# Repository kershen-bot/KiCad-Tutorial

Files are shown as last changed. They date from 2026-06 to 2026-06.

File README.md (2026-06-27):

# KiCad-Tutorial
I followed a KiCad tutorial, and here is how it went.

First, the tutorial I used was made by Digikey. The link to the Digikey website is "https://www.digikey.ca/," and the link to the tutorial is.
1. https://www.youtube.com/watch?v=0WCi1rhueH4&list=PLEBQazB0HUyQ5YJSdCBb79orXaR3Uk5vm
2. https://www.youtube.com/watch?v=0Q6gU7-QqUg&list=PLEBQazB0HUyQ5YJSdCBb79orXaR3Uk5vm&index=2
3. https://www.youtube.com/watch?v=0MqHR6cU_y0&list=PLEBQazB0HUyQ5YJSdCBb79orXaR3Uk5vm&index=3
4. https://www.youtube.com/watch?v=KN3fHXhNkTU&list=PLEBQazB0HUyQ5YJSdCBb79orXaR3Uk5vm&index=4
5. https://www.youtube.com/watch?v=4YSZwcUSgJo&list=PLEBQazB0HUyQ5YJSdCBb79orXaR3Uk5vm&index=5
6. https://www.youtube.com/watch?v=zdieFtrvjew&list=PLEBQazB0HUyQ5YJSdCBb79orXaR3Uk5vm&index=6
7. https://www.youtube.com/watch?v=zMNGZAnHPts&list=PLEBQazB0HUyQ5YJSdCBb79orXaR3Uk5vm&index=7

The finished Project was these images of a water alarm.




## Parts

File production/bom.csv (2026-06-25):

Designator | Footprint | Quantity | Value | LCSC Part #
BZ1 | Buzzer_D30mm_H20mm_P15_668-1652-ND_AI-3035-TT-12V-R | 1 | Buzzer
C1 | C_Disc_D3.0mm_W1.6mm_P2.50mm | 1 | 1nF
D1 | LED_D5.0mm | 1 | LED_Small_Filled
J1 | BarrelJack_GCT_DCJ200-10-A_Horizontal | 1 | Jack-DC
J2 | TerminalBlock_Phoenix_PT-1,5-2-5.0-H_1x02_P5.00mm_Horizontal | 1 | Screw_Terminal_01x02
Q1 | TO-92_Inline | 1 | 2N7000
R1 | R_Axial_DIN0204_L3.6mm_D1.6mm_P5.08mm_Horizontal | 1 | 10M
R2 | R_Axial_DIN0204_L3.6mm_D1.6mm_P5.08mm_Horizontal | 1 | 6.8k

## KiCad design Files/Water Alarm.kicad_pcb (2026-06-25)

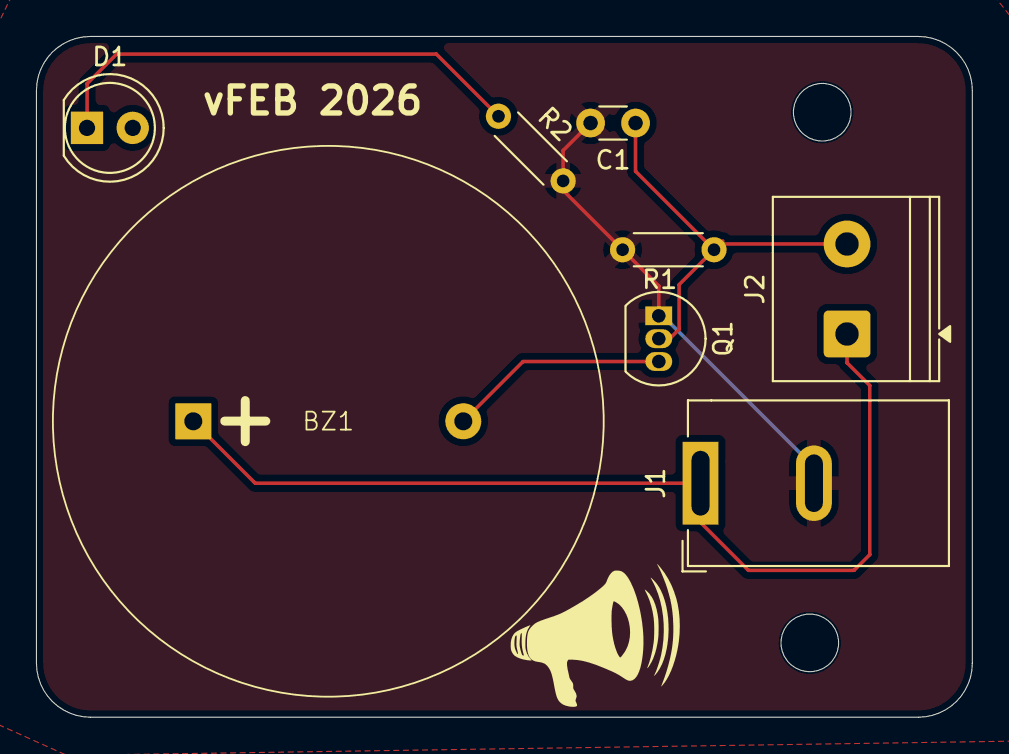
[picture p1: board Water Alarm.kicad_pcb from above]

Board: 2 copper layers, 52.0 x 37.8 mm, 8 parts (0 on the bottom side), 5 nets.

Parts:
BZ1: Buzzer; Buzzer_D30mm_H20mm_P15_668-1652-ND_AI-3035-TT-12V-R
C1: 1nF; C_Disc_D3.0mm_W1.6mm_P2.50mm
D1: LED_Small_Filled; LED_D5.0mm
J1: Jack-DC; BarrelJack_GCT_DCJ200-10-A_Horizontal
J2: Screw_Terminal_01x02; TerminalBlock_Phoenix_PT-1,5-2-5.0-H_1x02_P5.00mm_Horizontal
Q1: 2N7000; TO-92_Inline
R1: 10M; R_Axial_DIN0204_L3.6mm_D1.6mm_P5.08mm_Horizontal
R2: 6.8k; R_Axial_DIN0204_L3.6mm_D1.6mm_P5.08mm_Horizontal

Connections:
/Gate: C1.1, J2.2, Q1.2 (G), R1.1
GND: C1.2, J1.2, Q1.1 (S), R1.2, R2.2
unnamed: BZ1.2 (-), Q1.3 (D)
unnamed: D1.1 (K), R2.1
VCC: BZ1.1 (+), D1.2 (A), J1.1, J2.1
